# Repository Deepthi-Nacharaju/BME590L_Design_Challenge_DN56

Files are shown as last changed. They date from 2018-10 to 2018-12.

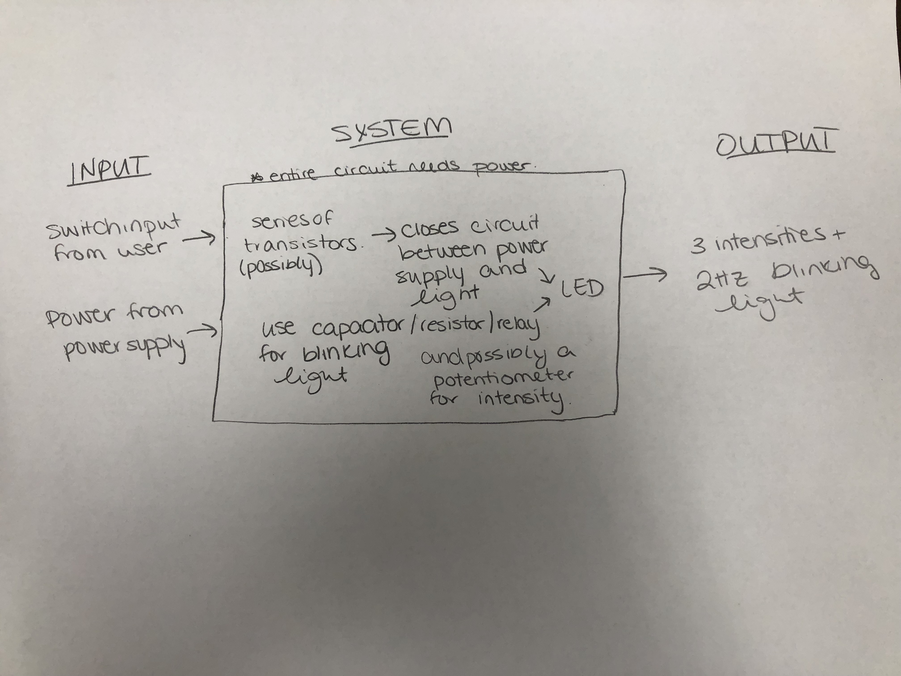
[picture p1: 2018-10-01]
Design Specs/IMG_6201.JPG

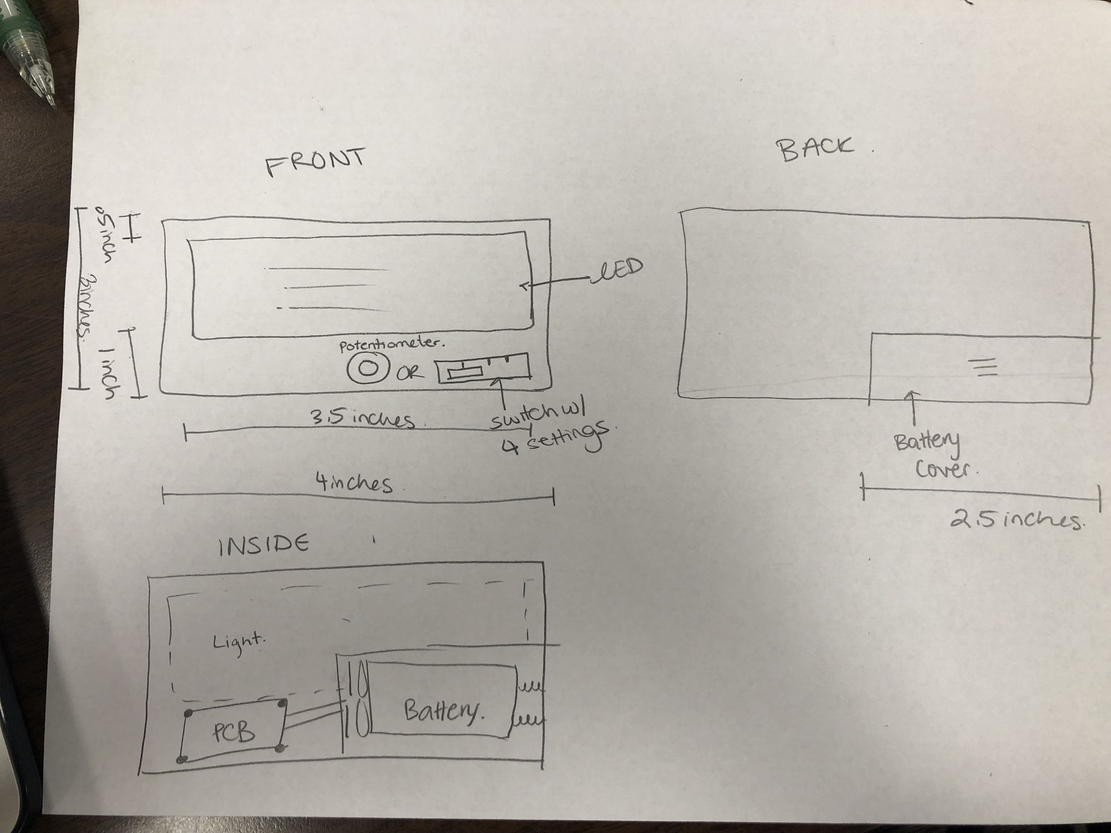
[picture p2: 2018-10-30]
Design Specs/Block_Diagram.JPG

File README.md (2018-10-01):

# BME590_Design_Challenge_DN56
# This Design Skills Challenge will test our knowledge of mechanical, electrical, and software design.

# Functional Specs are as follows

# LED light that is button-activated to switch between the following operating modes:
# Off
# Brightest
# Intermediate Brightness
# Least Bright
# Flashing @ 2 Hz
# Self-contained device with LED and button exposed.
# Extra credit possibilities:
# Battery life indicator
# Waterproof enclosure

# Constraints are as follows

# Run on single battery up to 9 V
# Electronics connected to a single PCB (can be single- or double-sided)
# Cannot weight more than 1 lb
# Cannot have a single dimension > 6 in
# Cannot cost more than $50 to duplicate unit
# Battery must be easily replaceable

# Projects will be evaluated according to the following criteria
# Minimize weight

# Minimize size

# Maximize Brightest mode

# Minimize power draw / maximize battery life

# Survive 3 foot drop with battery installed

# Create-and-maintain a GitHub project repository to maintain version history of:

# Mechanical CAD (PDFs + more)
# Electronic CAD (PDFs + more)
# Software
# Testing data
# Design history / notes
# Specification sheets
# Usage notes (README.md)
# Kanban board / Issues / Milestones

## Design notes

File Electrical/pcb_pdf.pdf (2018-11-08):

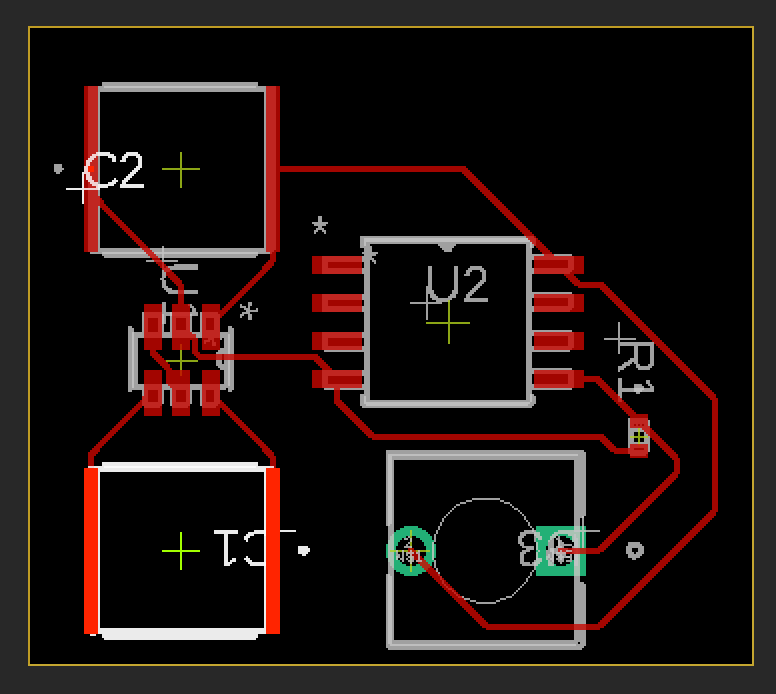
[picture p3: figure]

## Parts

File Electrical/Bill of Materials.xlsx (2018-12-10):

Bill of Materials
Item | Part Number | Supplier | Unit Cost | Number | Total | Notes
ATTINY85 | ATTINY85-20SURTR-ND | Digikey | $1.02 | 1 | $1.02 | Microcontroller
IC REG SWITCHD CAP 3.3V SOT23 | 296-39168-2-ND | Digikey | $0.52 | 1 | $0.52 | Voltage Regulator
10uF Capacitor | GRJ155R60J106ME11D‎ | Digikey | $0.25 | 3 | $0.75 | Capacitory
Green LED | ‎LTST-C191KGKT‎ | Digikey | $0.29 | 1 | $0.29 | LED
10K Ohm Resistor | RR0510P-103-D | Digikey | $0.10 | 1 | $0.10 | Resistor
1.1k Ohm Resistor | ‎RR0816P-112-D | Digikey | $0.11 | 1 | $0.11 | Resistor
Slide Switch | ‎JS102011SCQN | Digikey | $0.72 | 1 | $0.72 | Power Switch
Battery Holder | ‎S8421-45R‎ | Digikey | $1.17 | 1 | $1.17 | Battery Holder
CR2032 Battery | P189-ND | Digikey | $0.29 | 1 | $0.29 | 225mAh capacity
Self-Tapping 4 Size 1/2" Slotted Screw | 90053A110 | McMaster | $0.03 | 1 | $0.03 | Screw
 |  |  |  |  | $5.00

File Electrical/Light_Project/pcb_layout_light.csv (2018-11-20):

Part | Value | Device | Package | Description | DESCRIPTION | DIGI-KEY_PART_NUMBER | DIGI-KEY_PURCHASE_URL | MANUFACTURER_PART_NUMBER | MF | MP | PACKAGE | PROD_ID | VALUE | VENDOR
C1 | GRJ155R60J106ME11D | GRJ155R60J106ME11D | CAPC1005X55N | CAPACITOR CERAMIC MLCC 0402 10UF 6.3V SMD | Capacitor Ceramic Mlcc 0402 10uf 6.3v Smd | 490-13211-1-ND | https://www.digikey.com/product-detail/en/murata-electronics-north-america/GRJ155R60J106ME11D/490-13211-1-ND/5877419 |  | Murata | GRJ155R60J106ME11D | 0402 Murata
C2 | GRJ155R60J106ME11D | GRJ155R60J106ME11D | CAPC1005X55N | CAPACITOR CERAMIC MLCC 0402 10UF 6.3V SMD | Capacitor Ceramic Mlcc 0402 10uf 6.3v Smd | 490-13211-1-ND | https://www.digikey.com/product-detail/en/murata-electronics-north-america/GRJ155R60J106ME11D/490-13211-1-ND/5877419 |  | Murata | GRJ155R60J106ME11D | 0402 Murata
C3 | GRJ155R60J106ME11D | GRJ155R60J106ME11D | CAPC1005X55N | CAPACITOR CERAMIC MLCC 0402 10UF 6.3V SMD | Capacitor Ceramic Mlcc 0402 10uf 6.3v Smd | 490-13211-1-ND | https://www.digikey.com/product-detail/en/murata-electronics-north-america/GRJ155R60J106ME11D/490-13211-1-ND/5877419 |  | Murata | GRJ155R60J106ME11D | 0402 Murata
D1 | GREEN | LED-GREEN0603 | LED-0603 | Green SMD LED |  |  |  |  |  |  |  | DIO-00821 | GREEN
R1 | RR0510P-103-D | RR0510P-103-D | RES_0510 |  |  |  |  | RR0510P103D |  |  |  |  |  | Susumu
R2 | RR0816P-112-D | RR0816P-112-D | RES_0816 |  |  |  |  | RR0816P112D |  |  |  |  |  | Susumu
U1 | REG710NA-3.3/3K | REG710NA-3.3/3K | DBV6 |  |  |  |  | REG710NA3.33K |  |  |  |  |  | Texas Instruments
U2 | ATTINY85V-10SU | ATTINY85V-10SU | 8S2 |  |  |  |  | ATTINY85V10SU |  |  |  |  |  | Atmel
U3 | FSM8JRT | FSM8JRT | SWITCH_FSM4JRT |  |  |  |  | FSM8JRT |  |  |  |  |  | TE Connectivity

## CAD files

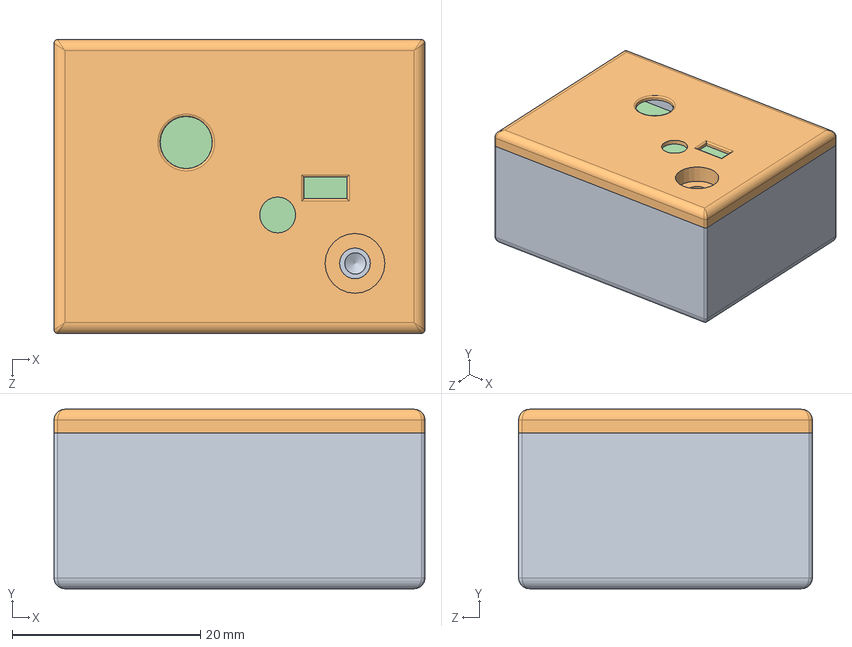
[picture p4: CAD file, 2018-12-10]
Mechanical/blinkylightasm.SLDASM
39.4 x 19.0 x 31.2 mm
Box_Bottom
Box_Top
coin_cell
pcb_light

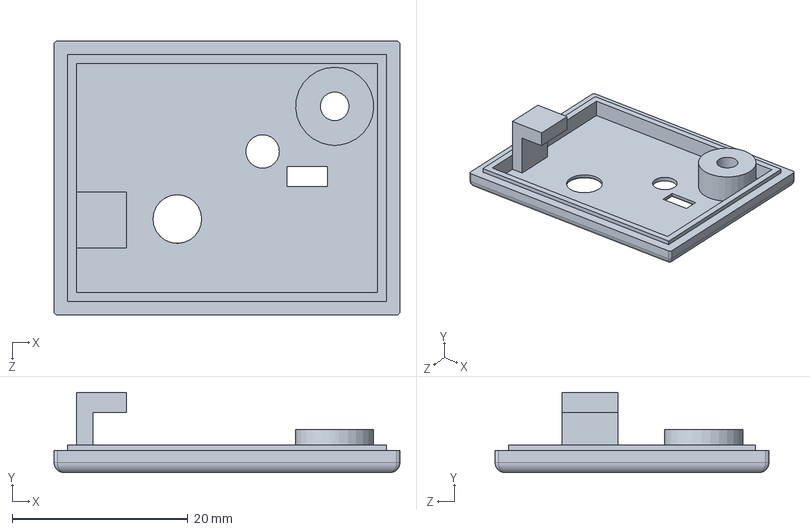
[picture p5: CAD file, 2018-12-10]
Mechanical/Box_Top.SLDPRT
39.4 x 9.14 x 31.2 mm

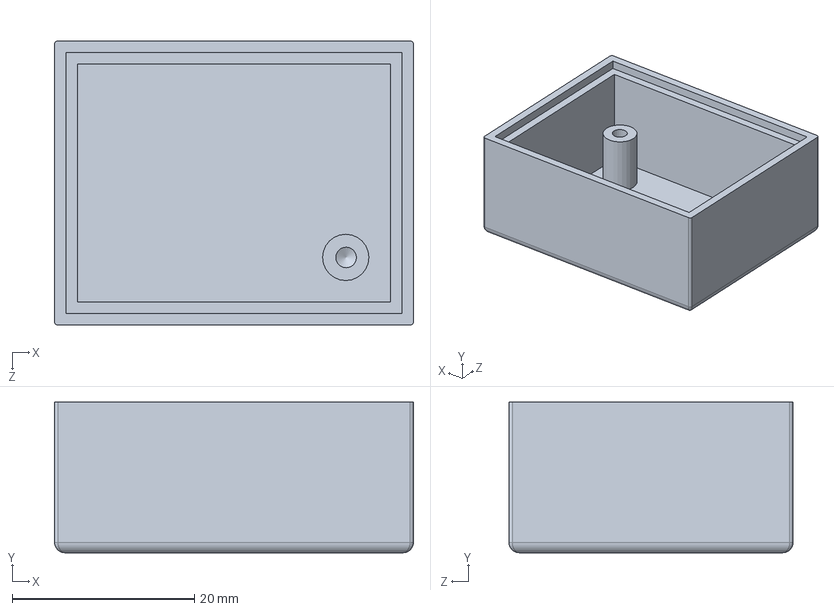
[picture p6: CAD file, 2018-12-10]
Mechanical/Box_Bottom.SLDPRT
39.4 x 16.5 x 31.2 mm

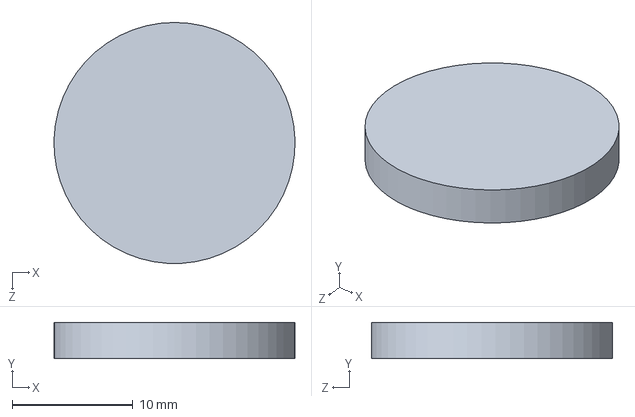
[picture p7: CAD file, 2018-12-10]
Mechanical/coin_cell.SLDPRT
20.0 x 3.00 x 20.0 mm

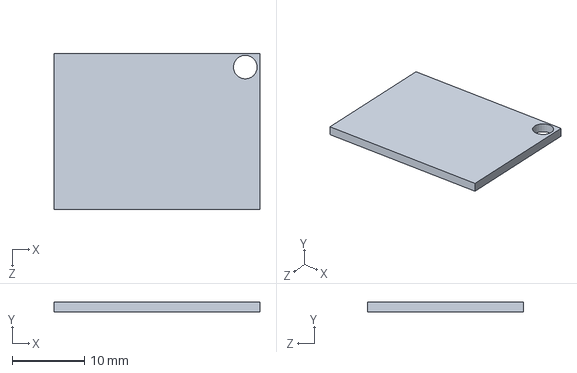
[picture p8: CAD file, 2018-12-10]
Mechanical/pcb_light.SLDPRT
28.4 x 1.40 x 21.6 mm

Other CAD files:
Mechanical/Box_Top_12_7.STL
Mechanical/Box_Bottom_12_7.STL
Mechanical/Box_Drawing.SLDDRW

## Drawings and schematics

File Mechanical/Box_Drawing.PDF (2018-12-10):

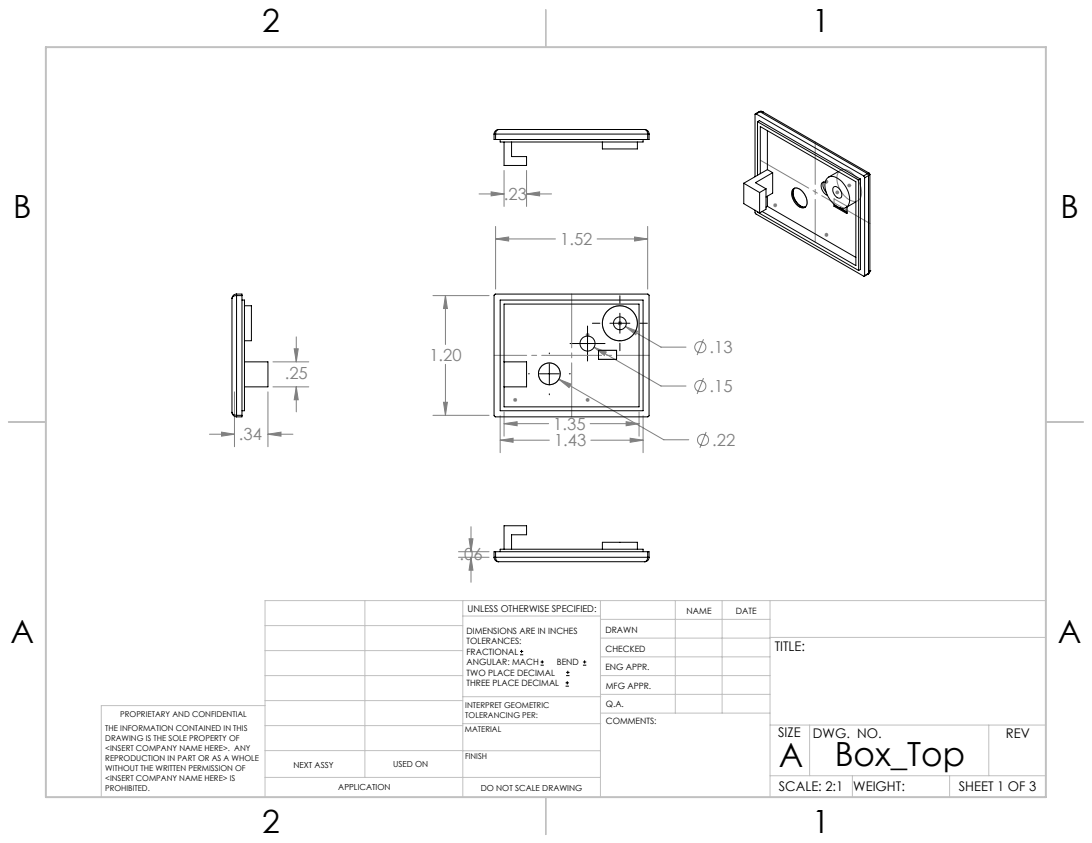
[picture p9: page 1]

UNLESS OTHERWISE SPECIFIED: | | NAME | DATE
DIMENSIONS ARE IN INCHES TOLERANCES: FRACTIONAL ANGULAR: MACH BEND TWO PLACE DECIMAL THREE PLACE DECIMAL | DRAWN

CHECKED | | | TITLE:

ENG APPR.
MFG APPR.

INTERPRET GEOMETRIC TOLERANCING PER: | Q.A.
MATERIAL | | SIZE A | DWG. NO. Box_Top | REV

PROPRIETARY AND CONFIDENTIAL
THE INFORMATION CONTAINED IN THIS
DRAWING IS THE SOLE PROPERTY OF
<INSERT COMPANY NAME HERE>. ANY
REPRODUCTION IN PART OR AS A WHOLE
WITHOUT THE WRITTEN PERMISSION OF
<INSERT COMPANY NAME HERE> IS
PROHIBITED.

NEXT ASSY | USED ON | FINISH

APPLICATION | DO NOT SCALE DRAWING | | SCALE: 2:1 | WEIGHT: | SHEET 1 OF 3

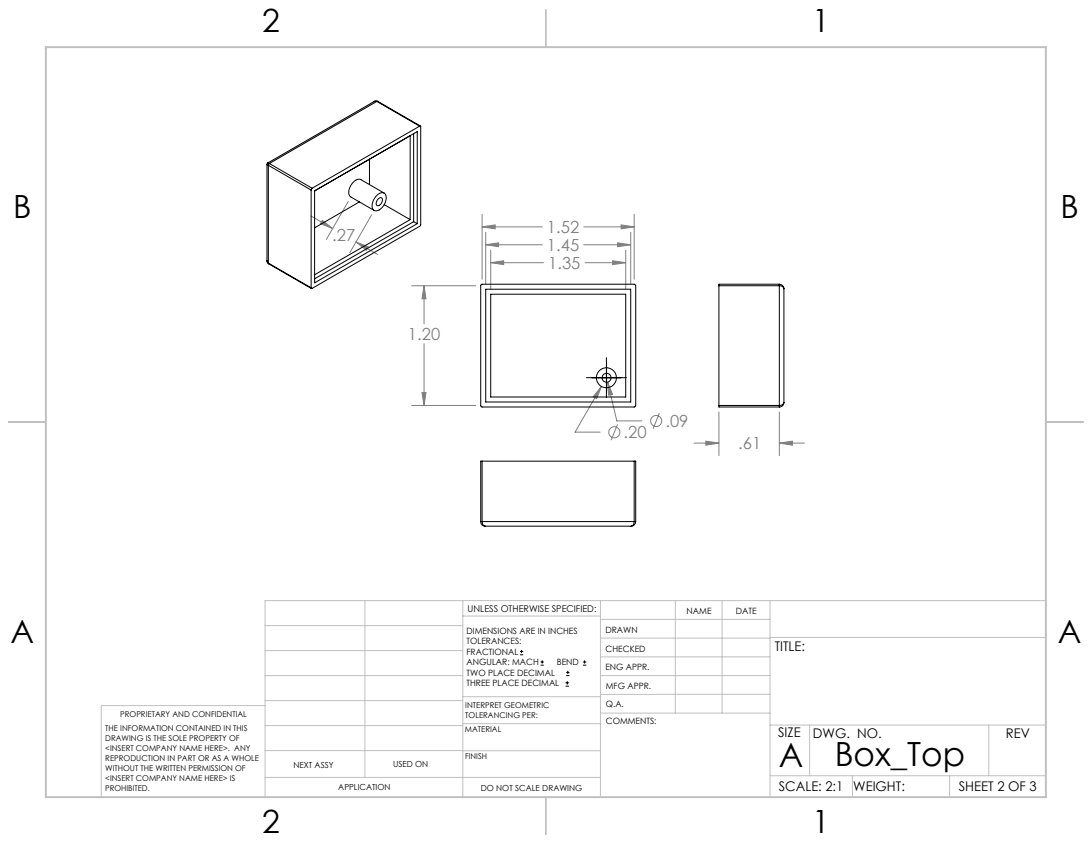
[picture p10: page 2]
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

CHECKED | | | TITLE:

ENG APPR.
MFG APPR.

INTERPRET GEOMETRIC TOLERANCING PER: | Q.A.
MATERIAL | | SIZE A | DWG. NO. Box_Top | REV

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

NEXT ASSY | USED ON | FINISH

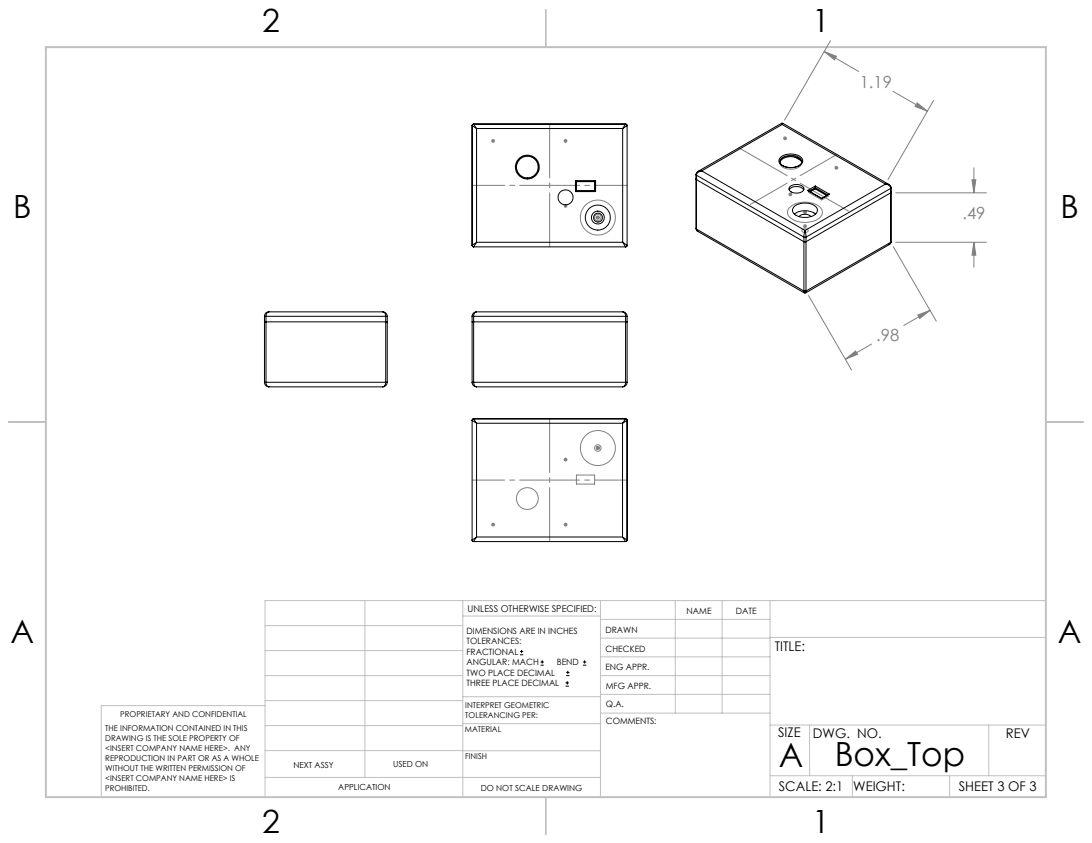
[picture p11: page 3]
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

CHECKED | | | TITLE:

ENG APPR.
MFG APPR.

INTERPRET GEOMETRIC TOLERANCING PER: | Q.A.
MATERIAL | | SIZE A | DWG. NO. Box_Top | REV

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

NEXT ASSY | USED ON | FINISH

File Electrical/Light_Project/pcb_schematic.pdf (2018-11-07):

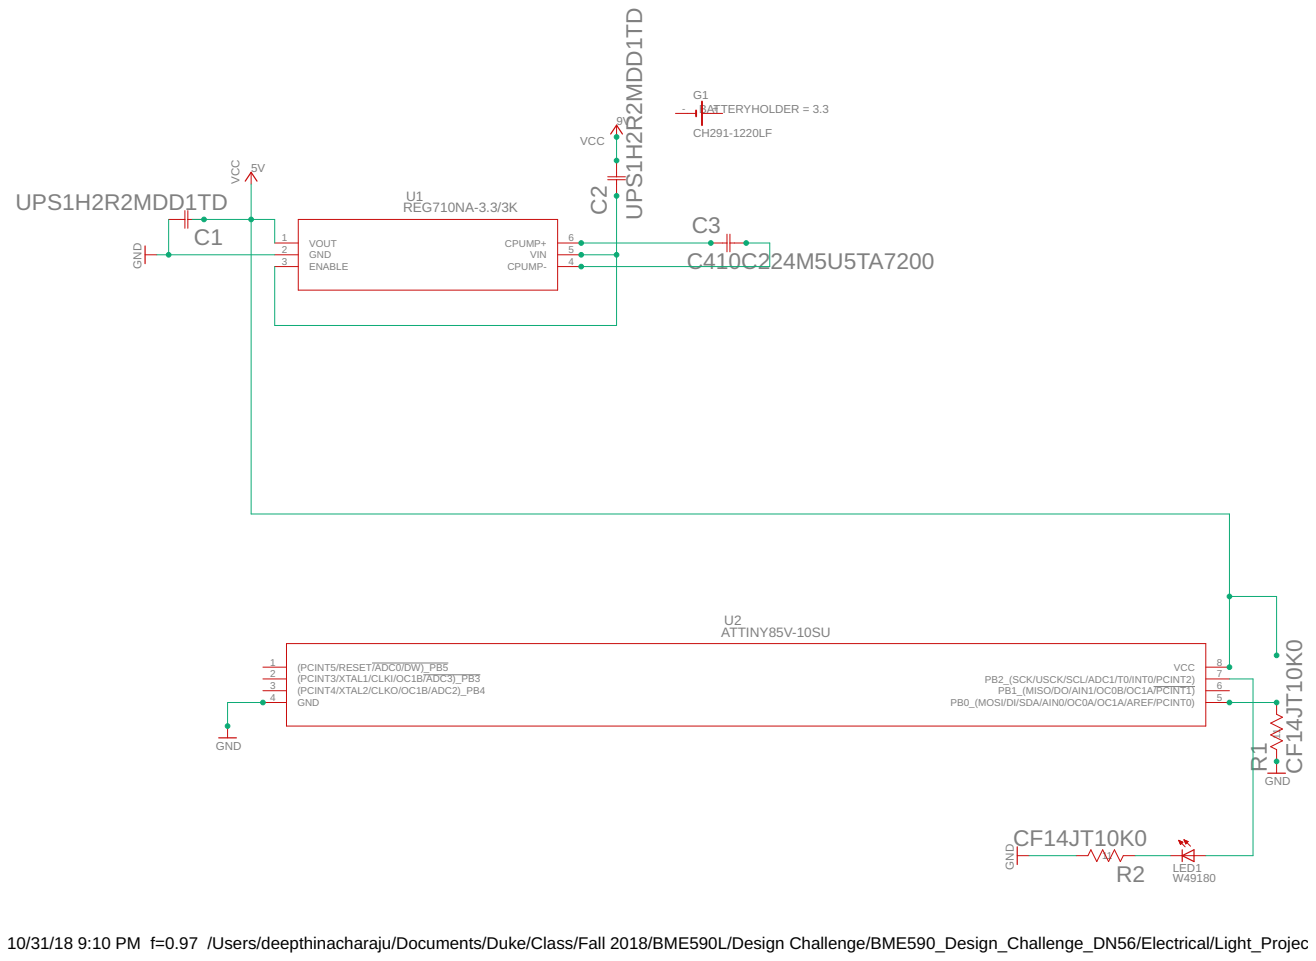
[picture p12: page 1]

10/31/18 9:10 PM f=0.97 /Users/deepthinacharaju/Documents/Duke/Class/Fall 2018/BME590L/Design Challenge/BME590_Design_Challenge_DN56/Electrical/Light_Project/pcb_schematic.sch (Sheet: 1/1)

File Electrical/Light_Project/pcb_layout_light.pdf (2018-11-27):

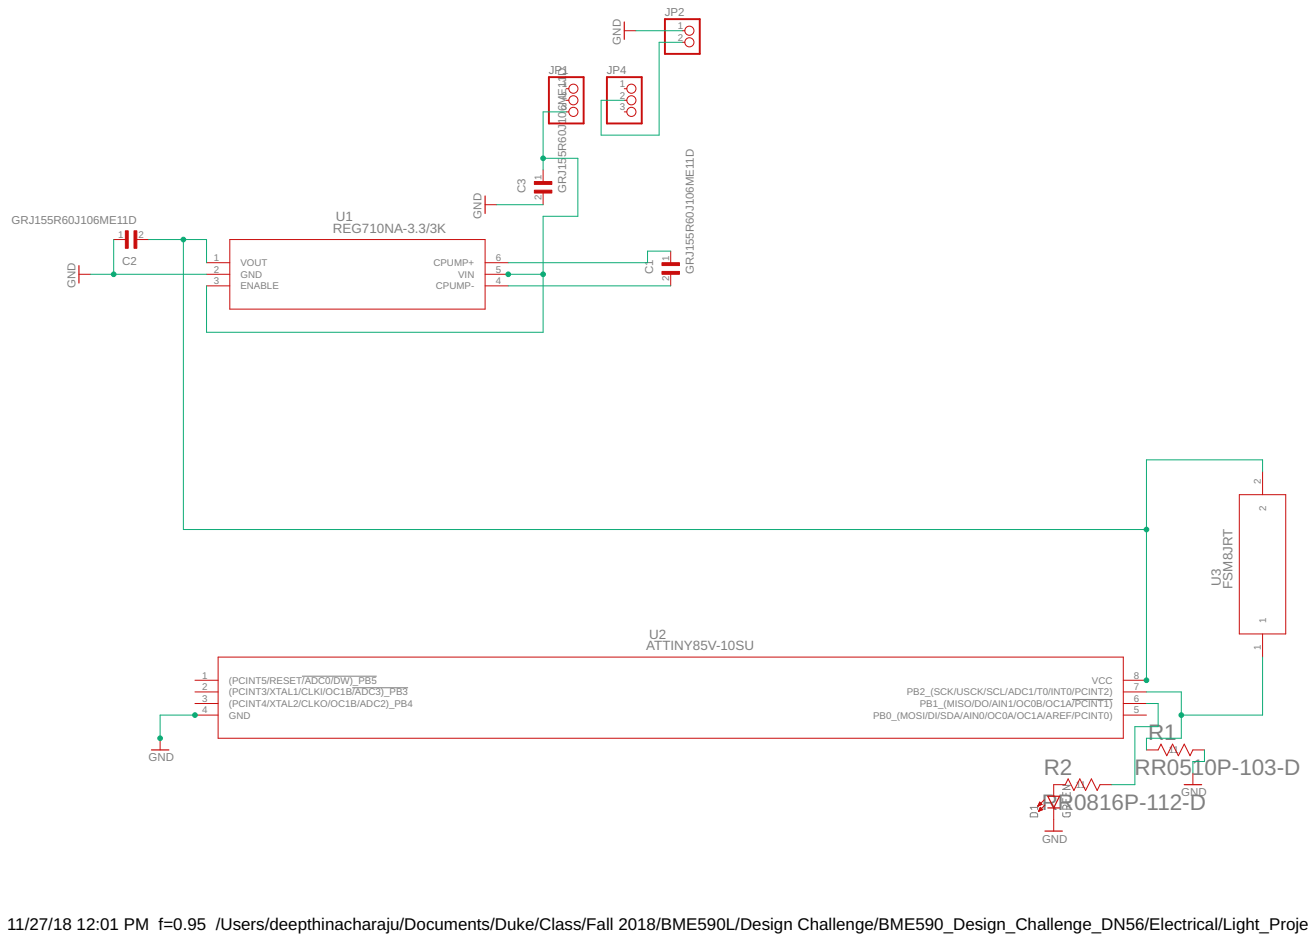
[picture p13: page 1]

11/27/18 12:01 PM f=0.95 /Users/deepthinacharaju/Documents/Duke/Class/Fall 2018/BME590L/Design Challenge/BME590_Design_Challenge_DN56/Electrical/Light_Project/pcb_layout_light.sch (Sheet: 1/1)

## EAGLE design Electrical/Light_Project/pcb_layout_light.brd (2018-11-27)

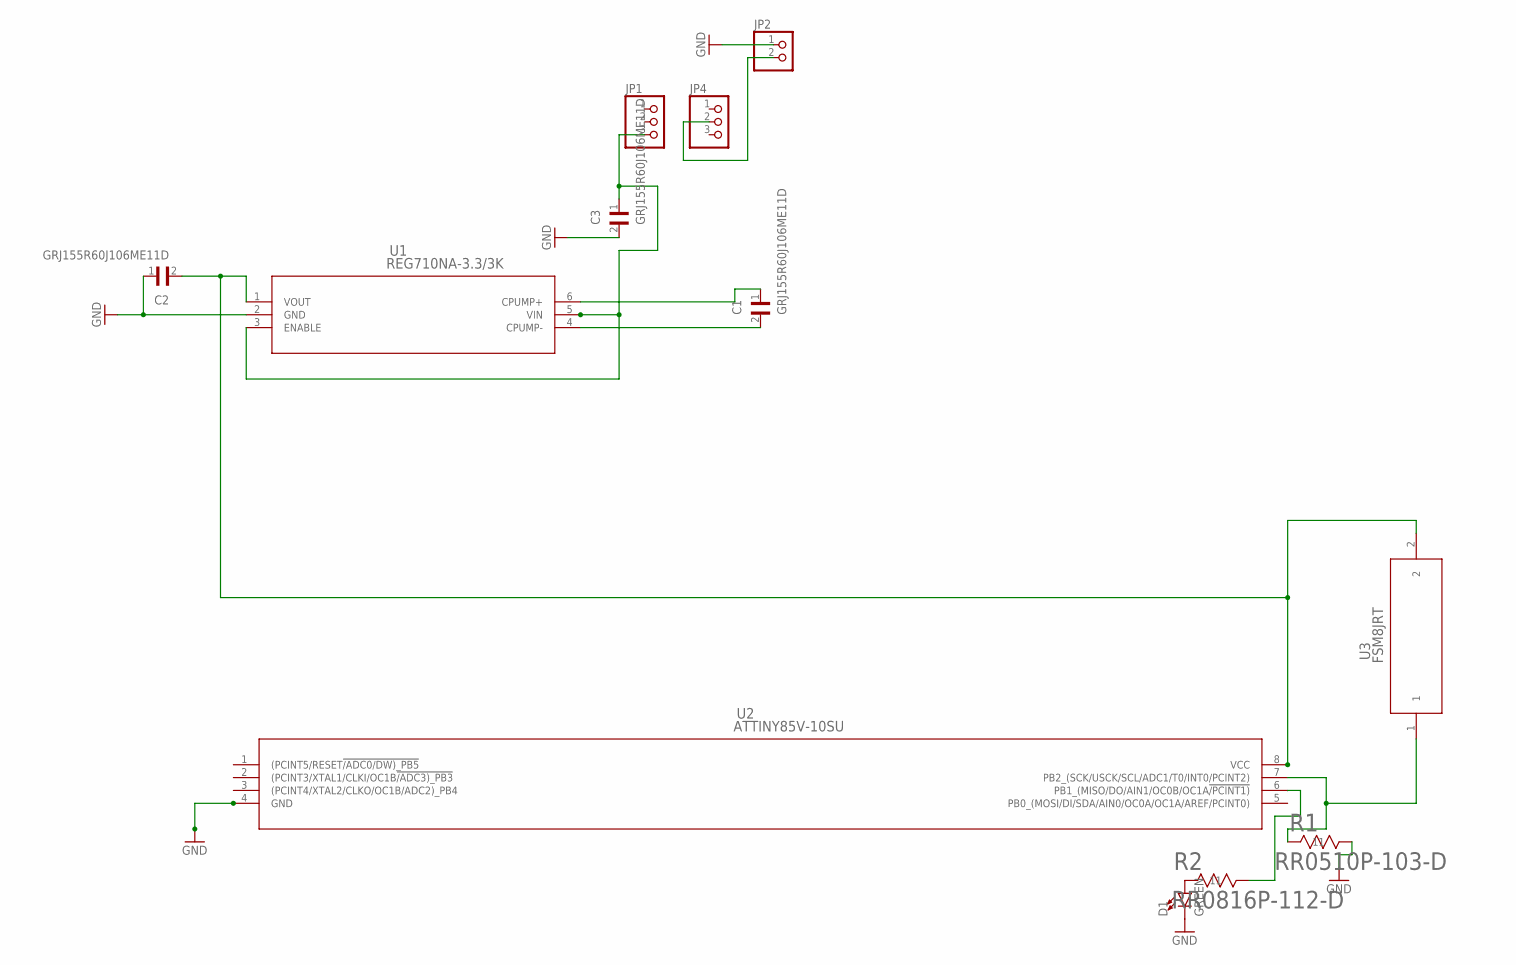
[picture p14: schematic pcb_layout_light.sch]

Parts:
C1, C2, C3: GRJ155R60J106ME11D; CAPC1005X55N
D1: GREEN; LED-0603
JP1, JP4: PINHD-1X3; 1X03
JP2: PINHD-1X2; 1X02
R1: RR0510P-103-D; RES_0510
R2: RR0816P-112-D; RES_0816
U1: REG710NA-3.3/3K; DBV6
U2: ATTINY85V-10SU; 8S2
U3: FSM8JRT; SWITCH_FSM4JRT

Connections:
GND: C2.1, C3.2, D1.C, JP2.1, R1.2 (22), U1.2 (GND), U2.4 (GND)
unnamed: C2.2, U1.1 (VOUT), U2.8 (VCC), U3.2
unnamed: C1.1, U1.6 (CPUMP+)
unnamed: C1.2, U1.4 (CPUMP-)
unnamed: R1.1 (11), U2.7 (PB2_(SCK/USCK/SCL/ADC1/T0/INT0/PCINT2)), U3.1
unnamed: D1.A, R2.1 (11)
unnamed: R2.2 (22), U2.6 (PB1_(MISO/DO/AIN1/OC0B/OC1A!/PCINT1))
unnamed: C3.1, JP1.3, U1.3 (ENABLE), U1.5 (VIN)
unnamed: JP2.2, JP4.2

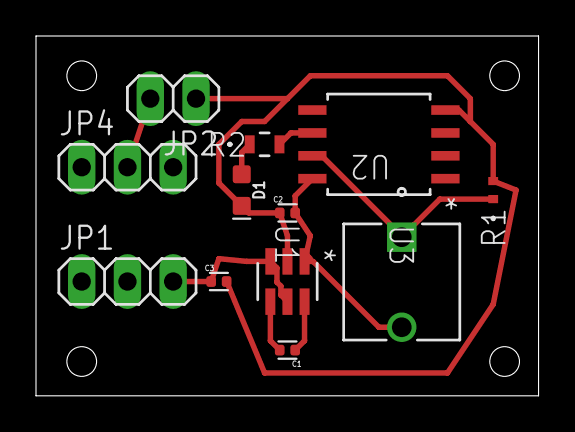
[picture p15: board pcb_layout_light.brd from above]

Board: 2 copper layers, 27.9 x 20.0 mm, 12 parts (0 on the bottom side), 9 nets.

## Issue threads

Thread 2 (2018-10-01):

MILESTONE TWO - Create Block Diagram

Deepthi-Nacharaju, 2018-10-01:
Sketch out a functional block diagram for your device. Be sure to include:
What functional blocks require power.
Inputs / outputs from the device.
How you will achieve the different light settings, including the blinking.
Sketch a physical design for your device, including:
Relevant approximate dimensions.
Mounting points for internal parts.
Access for battery.
Consider what aspects of the device need to be accessible to the user during operation.
The physical design sketches can be done by hand (paper-and-pencil drawings) or using CAD software (CAD software will ultimately be used, but can be slower when generating initial designs).

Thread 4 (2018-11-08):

Milestone 4

Deepthi-Nacharaju, 2018-11-08:
Updated PCB layout

Deepthi-Nacharaju, 2018-11-08:
my pcb is missing the LED because I can't find an eagle file for it online or a part number in Matt's tables :(

brinnaebent, 2018-11-13:
Schematic- connections are fine.
PCB-routeing under/through parts should be avoided (esp. if we are in house manufacturing)
You don't have a polygon pour-this would make your life a lot easier with the routing.

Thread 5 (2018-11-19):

Milestone 5

Deepthi-Nacharaju, 2018-11-19:
Solidworks files can be found in Mechanical folder. Will be further refined when PCB is finalized and button and screw hole locations are known

ps178, 2018-11-21:
Hi Deepthi,

Your CAD looks good. I like how the top and bottom can snap onto each other. My one note is about the LED and button. There doesnt seem to be any holes or openings to interact with a button or see and LED. Also, the overall case is pretty small. What MCU are you using?

Deepthi-Nacharaju, 2018-11-21:
Hi Petek!

I still need to put the hole for the led and button in, I'm still working to finalize the routes on my pcb and once i do, I can measure those distances.

I'm using the ATTINY85 for my MCU

ps178, 2018-11-21:
Ok! Also, you might want to make your design bigger since you will have a battery

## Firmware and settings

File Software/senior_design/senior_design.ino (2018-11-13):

#include <avr/io.h>
#include <avr/interrupt.h>

#define LED 1
#define BUTTON 2
#define BLINK_RATE 2; //Hz

int PWM_MAX = 255;
int button_state = 0;
int old_button_state = 0;
// operating_mode: 0 - off, 1 - bright, 2 - midbright, 3 - dim, 4 - 2Hz
int operating_mode = 0;
int debounce_delay = 250;
int debounce_time = 0;
bool pin_mode = LOW;
bool _update = false;

void setup() {
  // put your setup code here, to run once:
  pinMode(LED, OUTPUT);
  digitalWrite(LED, LOW);
  pinMode(BUTTON, INPUT);
  GIMSK = 0b00100000;
  PCMSK = 0b0000100;
  sei();
}

void loop() {
  // put your main code here, to run repeatedly:
  debounce_check();
  Update_LED();
}

ISR(PCINT0_vect) {
  button_state += 1;
}

void debounce_check() {
  if (button_state - old_button_state > 1) {
    if (millis() - debounce_time > debounce_delay) {
      operating_mode += 1;
      operating_mode %= 5;
      _update = true;
      debounce_time = millis();
      old_button_state = button_state;
    }
  }
  //button_state%1000;
}

void SetBrightness(int intensity) {
  analogWrite(LED, intensity);
}

void Flash_Light() {
  for (int i = 0; i <= PWM_MAX / 2; i++) {
    SetBrightness(i);
    delay(1);
  }
  for (int i = PWM_MAX / 2 ; i >= 0; i--) {
    SetBrightness(i);
    delay(1);
  }
}

void Update_LED(){
    if (_update == true) {
    switch (operating_mode) {
      case 0:
        SetBrightness(0);
        break;
      case 1:
        SetBrightness(1);
        break;
      case 2:
        SetBrightness(10);
        break;
      case 3:
        SetBrightness(PWM_MAX);
        break;
      case 4:
        while(operating_mode == 4){
        Flash_Light();
        debounce_check();
        }
        break;
    }
    //delay(500);
    _update = false;
  }
}

void two_state_LED(){
   if ((_update == true) && (pin_mode == HIGH)){
    pin_mode = LOW;
    digitalWrite(LED, pin_mode);
    _update == false;
    delay(500);
  }
  else if ((_update == true) && (pin_mode == LOW)){
    pin_mode = HIGH;
    digitalWrite(LED, pin_mode);
    _update == false;
    delay(500);
  }
}

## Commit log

2018-10-28 Add EAGLE files and Block Diagram
    [pcb_schematic.sch]
2018-10-29 add pcb
    [pcb_layout_light.brd, pcb_layout_light.sch, pcb_schematic.brd]
2018-10-30 add arduino code
2018-11-01 milestone 3
    [Milestone_3_Schematic.sch]
2018-11-07 Route PCB (not optimized)
    [pcb_layout_light.brd, pcb_layout_light.sch, pcb_schematic.sch]
2018-11-08 use surface mount resistor in diagram
    [pcb_layout_light.brd, pcb_layout_light.sch]
2018-11-08 add pdf of new layout
    [pcb_layout_light.brd]
2018-11-08 add holes on pcb
    [pcb_layout_light.brd]
2018-11-13 update PCB layout with LED
    [pcb_layout_light.brd]
2018-11-19 add solidworks files for milestone 5
    [Box_Bottom.SLDPRT, Box_Top.SLDPRT, blinkylightasm.SLDASM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]
2018-11-20 add updated solidwords files with screws and nuts
    [90710A145_TYPE%2018-8%20SS%20THIN%20HEX%20NUT%20-%20DIN%20439B.SLDPRT, 92005A004_METRIC%20PAN%20HEAD%20PHILLIPS%20MACHINE%20SCREW.SLDPRT, Box_Bottom.SLDPRT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]
2018-11-20 change route width
    [pcb_layout_light.brd, pcb_layout_light.csv]
2018-11-27 Update bypass cap to go to ground and add header pins for switch and power supply
    [pcb_layout_light.brd, pcb_layout_light.sch]
2018-12-08 Add BOM
    [Bill of Materials.xlsx, pcb_layout_light.brd, pcb_layout_light.sch]
2018-12-10 Final solidworks files
    [90710A145_TYPE%2018-8%20SS%20THIN%20HEX%20NUT%20-%20DIN%20439B.SLDPRT, 92005A004_METRIC%20PAN%20HEAD%20PHILLIPS%20MACHINE%20SCREW.SLDPRT, Bill of Materials.xls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]

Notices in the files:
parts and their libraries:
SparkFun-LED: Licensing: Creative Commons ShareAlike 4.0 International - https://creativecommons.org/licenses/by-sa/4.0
